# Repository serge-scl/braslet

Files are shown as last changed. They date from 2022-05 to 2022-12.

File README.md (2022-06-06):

Here I have collected calculations and drawings of a project for creating a device for removing disposable medical gloves with subsequent storage, accounting and disposal. This procedure is necessary to avoid a significant risk of infection during the work of medical staff. Various visual aids here offer a written and illustrated procedure on how to properly remove a disposable glove to avoid contact with a contaminated surface. However, the human factor suggests that sooner or later a mistake happens. This possibility is exacerbated by the factor of fatigue and stress.
The root directory contains files where I make various calculations. The earliest calculations related to the overall dimensions of the bracelet and its details relative to the size of the coverage of a man's or woman's wrist. These calculations cannot be called accurate. These are just some starting points.
Another group of calculations concerned the ability to determine the forces that a pneumatic mechanism must create for successful operation. This calculation showed that the range can vary quite widely. In the future, using differential equations will allow us to find more optimal values.
And the third type of calculation is the calculation of the solenoid valve that controls the operation of the suction cup. I tried to verify these calculations as far as possible.
The designCAD folder contains drawings in an open format. This work has not yet been completed in its entirety. So far, there are no drawings of the case, the upper and lower parts of the entire device, and it remains to be done. In the upper part there will be a working niche with a bracelet, and receivers and micropumps working with it. At the bottom there will be a negative pressure fan and storage for used gloves. So far, only part of the drawings of the bracelet have been made. This is a vacuum chamber with a solenoid valve and part of a pneumatic drive. All this is still in the form of separate parts without assembly. In the near future, we plan to complete the vacuum line and pneumatic drive.
Kicad pcb will contain two PCBs in two separate projects. This is a power control unit for the suction cup valve and a sensor unit that registers the correct touch of the hand with the glove. How the PCBs are attached can be seen in the sub_asstmbly/solenoid_in_chamb01 file. The inputs and outputs of these blocks are made in such a way that various types of microcontrollers can be connected. I did not finish the topology of the circuits, since the type of connectors may still be different.

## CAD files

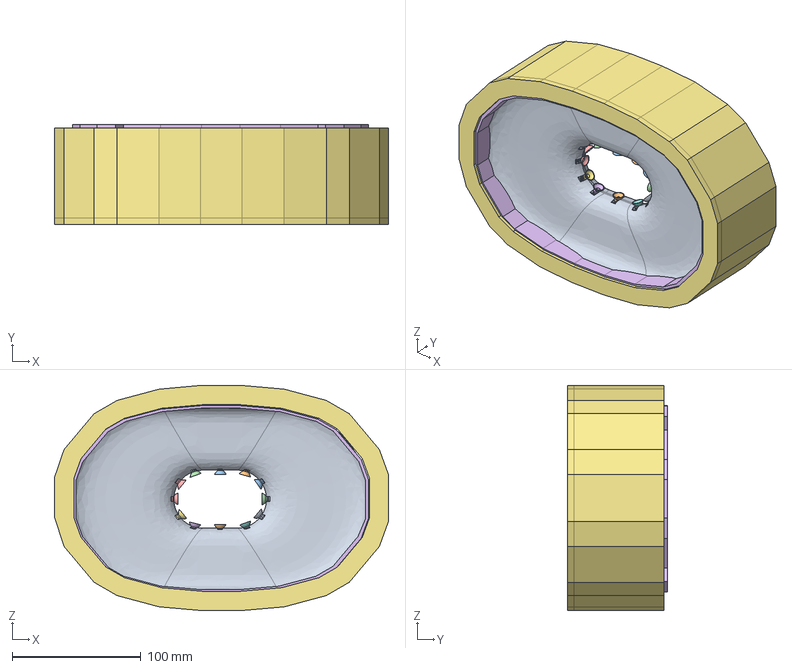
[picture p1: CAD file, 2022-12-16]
design CAD/sub_assembly/md_shell_asm01.FCStd
259.6 x 77.7 x 175.0 mm
lips02_001
cup04_001
cup04_002
cup04_003
cup04_004
cup04_005
cup04_006
cup04_007
cup04_008
cup04_009
cup04_010
cup04_011
cup04_012
btm_spr_modl_sh03_001
top_spr_modl_shell01_001

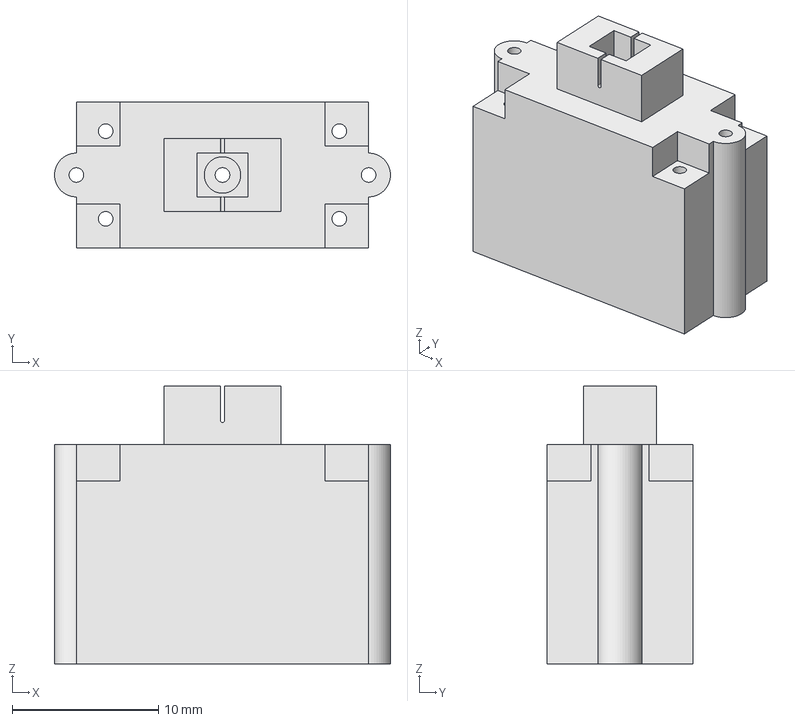
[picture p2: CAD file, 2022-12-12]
design CAD/shell_chamb12.FCStd
23.0 x 10.0 x 19.0 mm

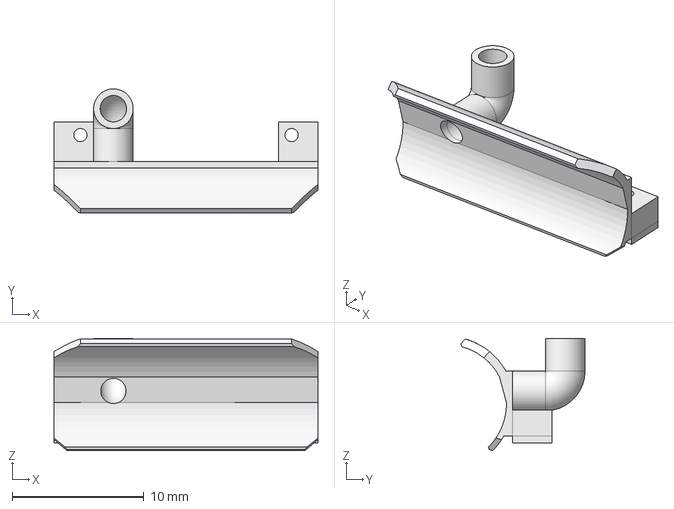
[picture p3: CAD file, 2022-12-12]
design CAD/actuator8_piston.FCStd
20.0 x 9.41 x 8.51 mm

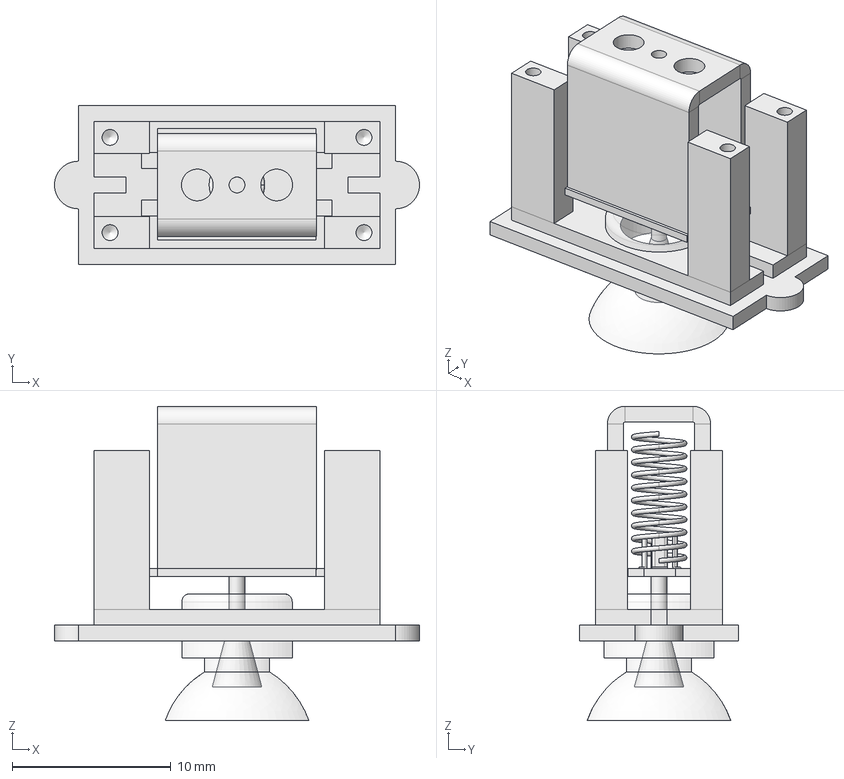
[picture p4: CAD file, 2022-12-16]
design CAD/sub_assembly/valve_floor_spr_scup01.FCStd
23.0 x 10.0 x 19.8 mm
suct_chamb_floor05_001
cup04_001
spring_valve01_001
tongue_sucker_001
el_magnetcore03_001
valve11_001

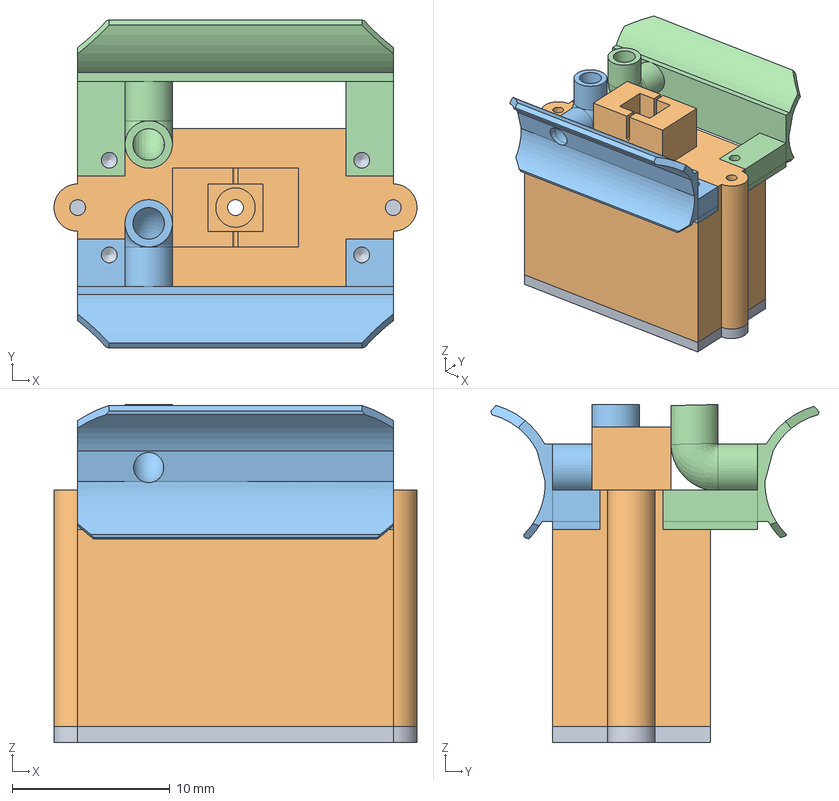
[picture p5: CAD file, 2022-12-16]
design CAD/sub_assembly/top_assmbl_vacuum_ch1.FCStd
23.0 x 20.8 x 21.4 mm
suct_chamb_floor05_001
shell_chamb12_001
actuator8_piston_001
actuator8_pistonPCBside_001

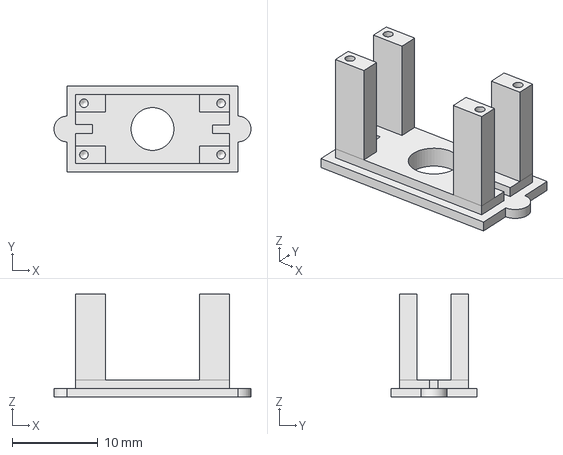
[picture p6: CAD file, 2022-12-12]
design CAD/suct_chamb_floor05.FCStd
23.0 x 10.0 x 12.0 mm

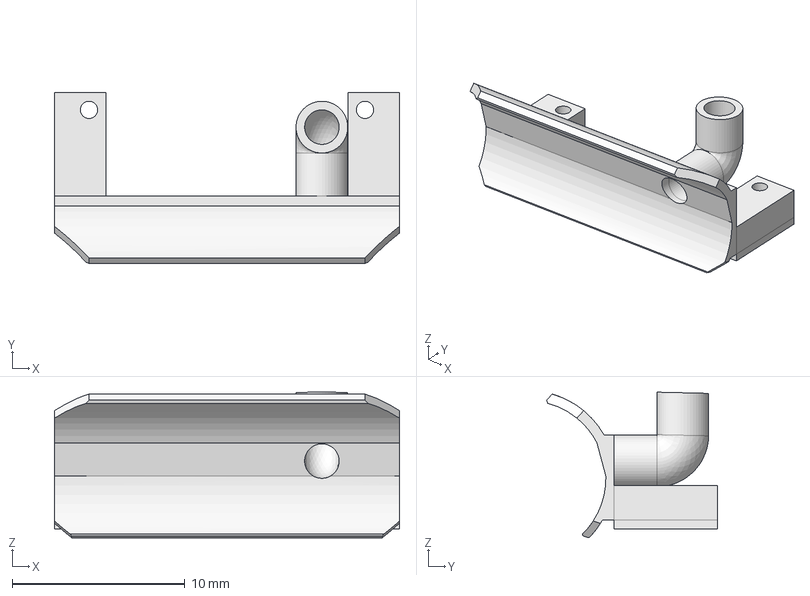
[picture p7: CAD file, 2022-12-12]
design CAD/actuator8_pistonPCBside.FCStd
20.0 x 9.90 x 8.45 mm

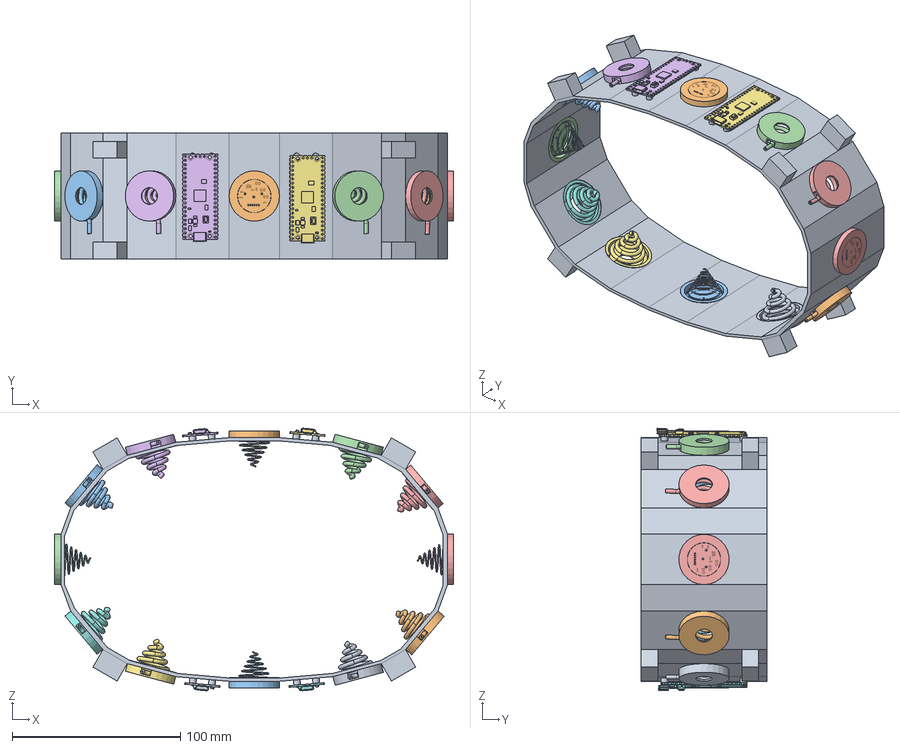
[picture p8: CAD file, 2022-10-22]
design CAD/sub_assembly/spr_mdl_bottm_cvr01.FCStd
237.4 x 75.0 x 156.3 mm
btm_spr_modl_sh03_001
con_spring_sens_sct01_001
con_spring_sens_sct01_002
con_spring_sens_sct01_003
con_spring_sens_sct01_004
con_spring_pip_sct01_001
con_spring_pip_sct01_002
con_spring_pip_sct01_003
con_spring_pip_sct01_004
con_spring_pip_sct01_005
con_spring_pip_sct01_006
con_spring_pip_sct01_007
con_spring_pip_sct01_008
Raspberry_Pi_Pico_001
Raspberry_Pi_Pico_002
Raspberry_Pi_Pico_003
Raspberry_Pi_Pico_004

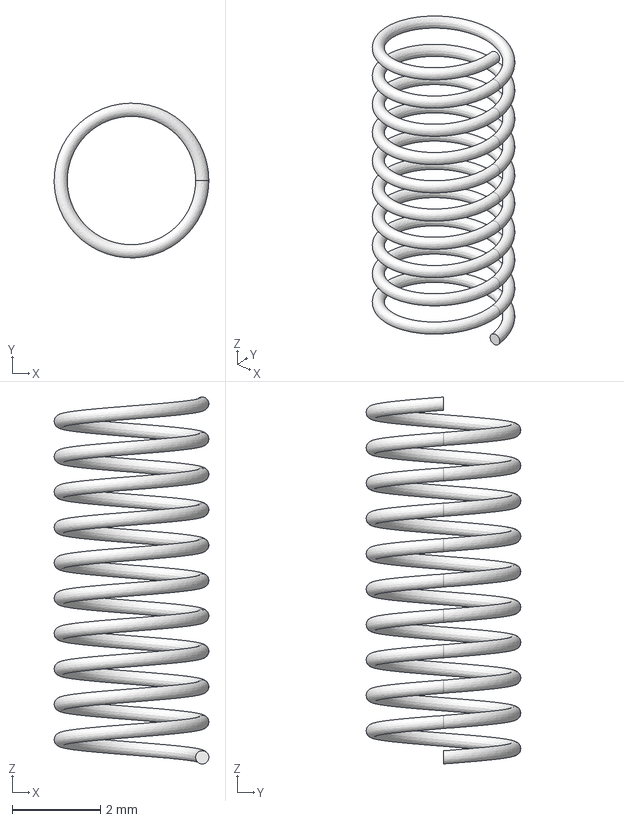
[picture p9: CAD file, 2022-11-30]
design CAD/spring_valve01.FCStd
3.50 x 3.50 x 8.30 mm

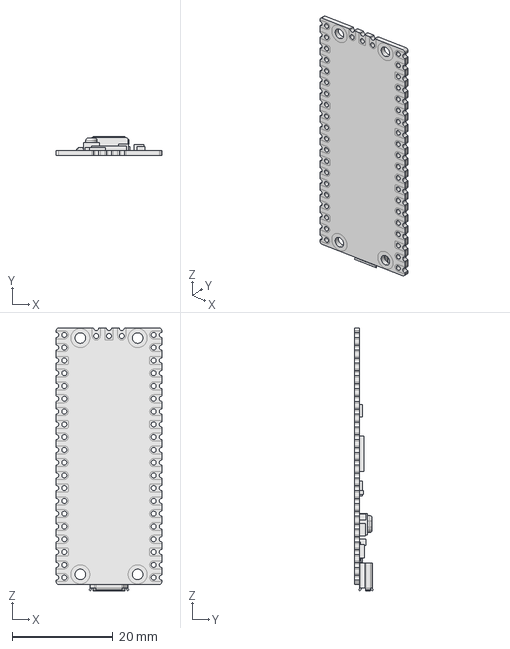
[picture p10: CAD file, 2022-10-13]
design CAD/sub_assembly/Raspberry_Pi_Pico.FCStd
21.0 x 3.73 x 52.3 mm

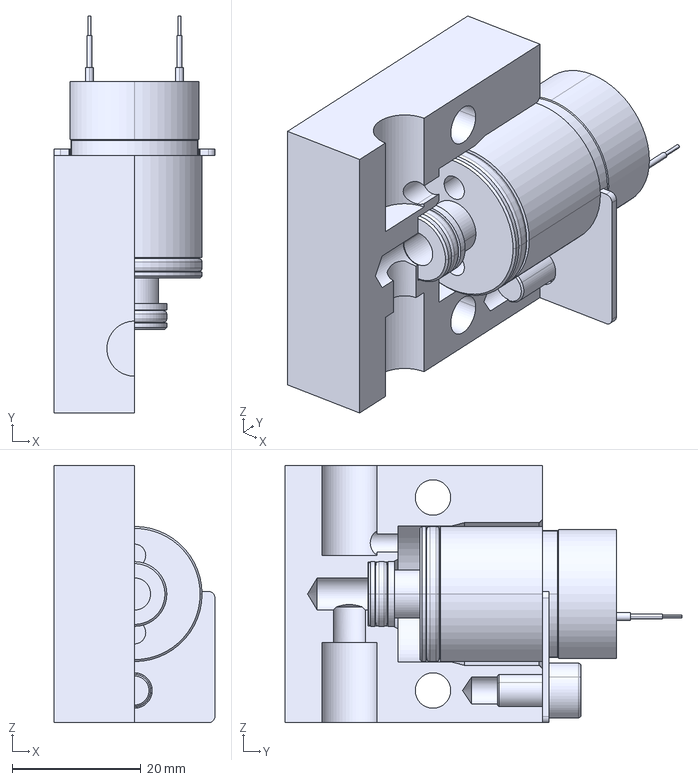
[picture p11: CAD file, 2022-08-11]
design CAD/sub_assembly/va_204_1_mont_plt.FCStd
25.0 x 61.7 x 40.0 mm

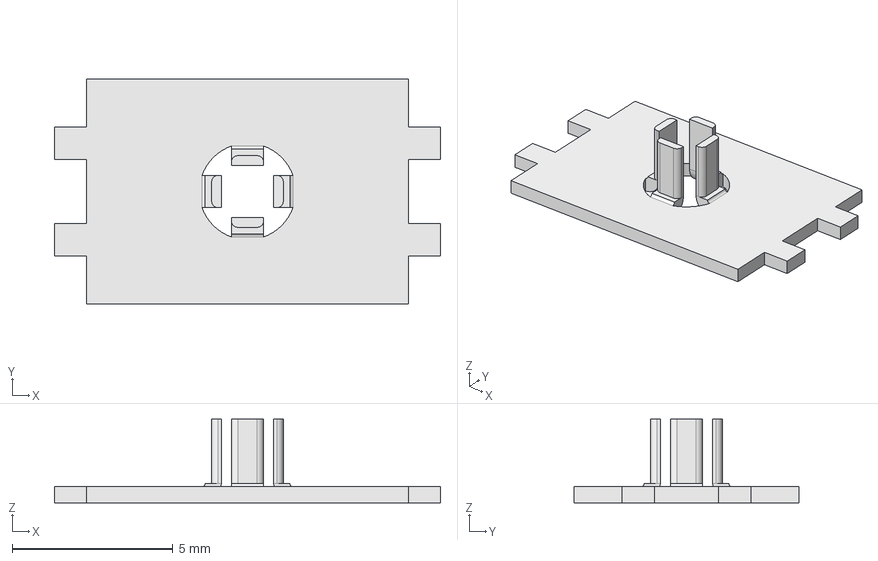
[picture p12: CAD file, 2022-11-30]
design CAD/valve11.FCStd
12.0 x 7.00 x 2.60 mm

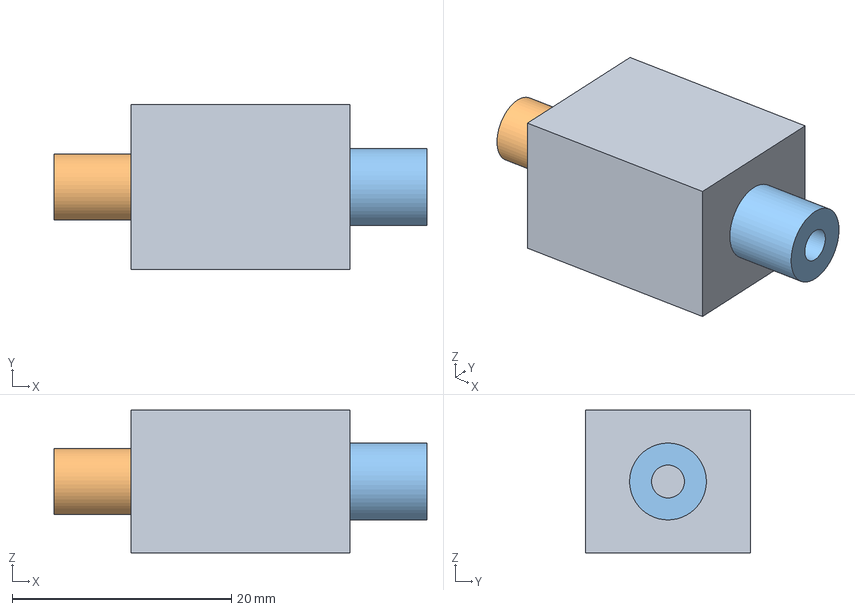
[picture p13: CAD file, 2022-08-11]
design CAD/sub_assembly/valve0520D.FCStd
34.0 x 15.0 x 13.0 mm
Tube
Tube001

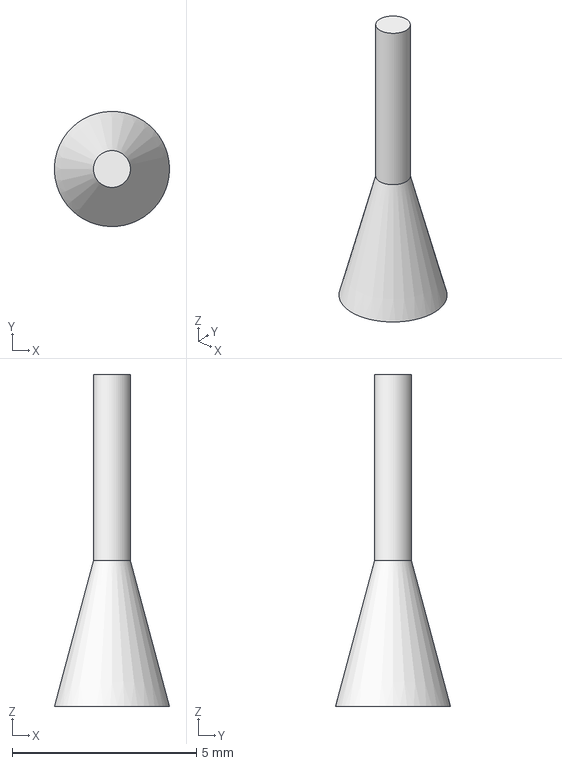
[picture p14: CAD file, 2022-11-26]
design CAD/tongue_sucker.FCStd
3.12 x 3.12 x 9.00 mm

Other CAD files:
design CAD/cup04.FCStd
design CAD/sub_assembly/claster_feed_ring03.FCStd
design CAD/btm_spr_modl_sh03.FCStd
design CAD/sub_assembly/con_spring_pip_sct01.FCStd
design CAD/actuator8.FCStd
design CAD/actuator8_side.FCStd
design CAD/branch_pipe_tee01.FCStd
design CAD/branch_pipe_tee0_feeder01.FCStd
design CAD/bush_feeder03.FCStd
design CAD/bush_simply02.FCStd
design CAD/coil_pins01.FCStd
design CAD/coil_pins02.FCStd
design CAD/con_pip_spring_sokt01.FCStd
design CAD/con_spring_plp01.FCStd
design CAD/con_spring_sockt01.FCStd
design CAD/con_spring_stl01.FCStd
design CAD/el_magnetcore03.FCStd
design CAD/frame_spring03.FCStd
design CAD/lips02.FCStd
design CAD/magn_coil03.FCStd
design CAD/pin_spring_fix01.FCStd
design CAD/pip_feed_ring05.FCStd
design CAD/pip_feed_ring06.FCStd
design CAD/screw01.FCStd
design CAD/spring_stop_01.FCStd
design CAD/sub_assembly/Ring_pneum_act01.FCStd
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

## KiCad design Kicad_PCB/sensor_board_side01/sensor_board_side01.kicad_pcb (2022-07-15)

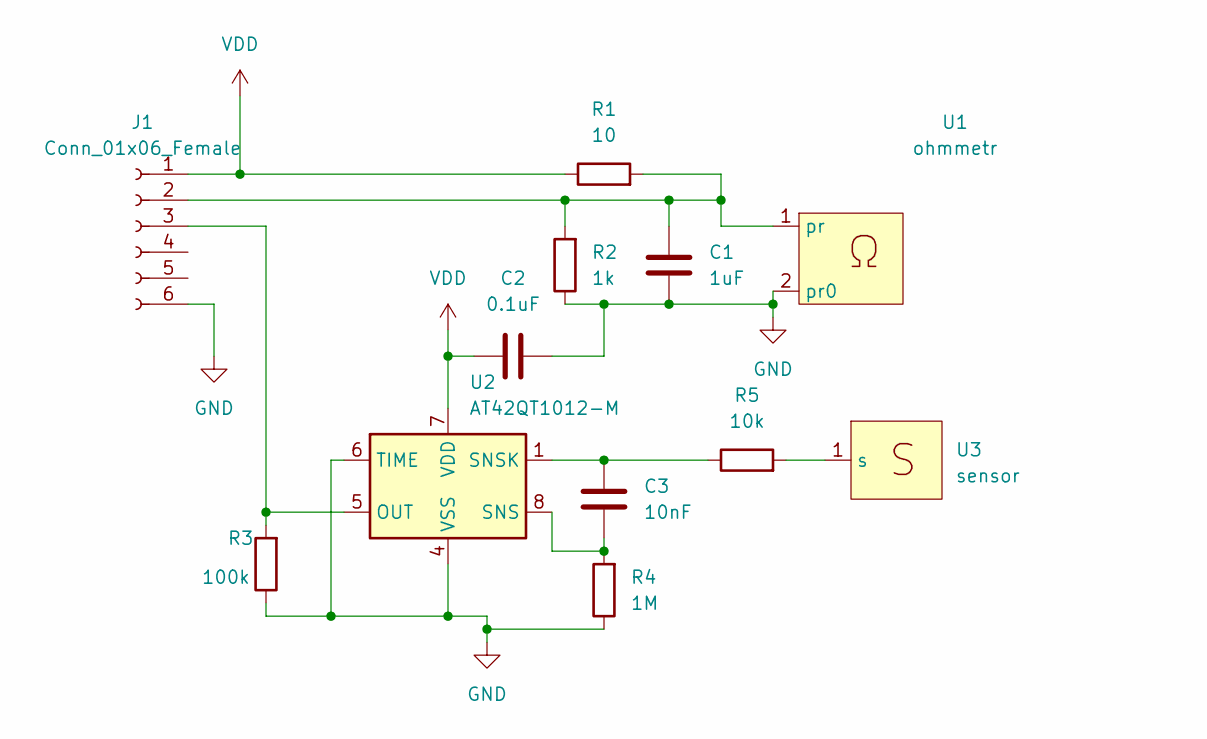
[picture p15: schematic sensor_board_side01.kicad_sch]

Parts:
C1: 1uF; C_0805_2012Metric
C2: 0.1uF; C_0805_2012Metric
C3: 10nF; C_0805_2012Metric
J1: Conn_01x06_Female; Hirose_DF13-06P-1.25DSA_1x06_P1.25mm_Vertical
R1: 10; R_0402_1005Metric
R2: 1k; R_0402_1005Metric
R3: 100k; R_0402_1005Metric
R4: 1M; R_0402_1005Metric
R5: 10k; R_0402_1005Metric
U1: ohmmetr; ohm_metr
U2: AT42QT1012-M; DFN-8-1EP_2x2mm_P0.5mm_EP0.9x1.5mm
U3: sensor; toch_sens

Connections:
GND: C1.2, C2.2, J1.6, R2.1, R3.1, R4.1, U1.2 (pr0), U2.4 (VSS), U2.6 (TIME), U2.9 (VSS)
unnamed: C1.1, J1.2, R1.2, R2.2, U1.1 (pr)
unnamed: C3.1, R4.2, U2.8 (SNS)
unnamed: C3.2, R5.1, U2.1 (SNSK)
unnamed: J1.3, R3.2, U2.5 (OUT)
unnamed: R5.2, U3.1 (s)
VDD: C2.1, J1.1, R1.1, U2.7 (VDD)

Board: 2 copper layers, 12 parts (1 on the bottom side), 7 nets, no tracks yet.

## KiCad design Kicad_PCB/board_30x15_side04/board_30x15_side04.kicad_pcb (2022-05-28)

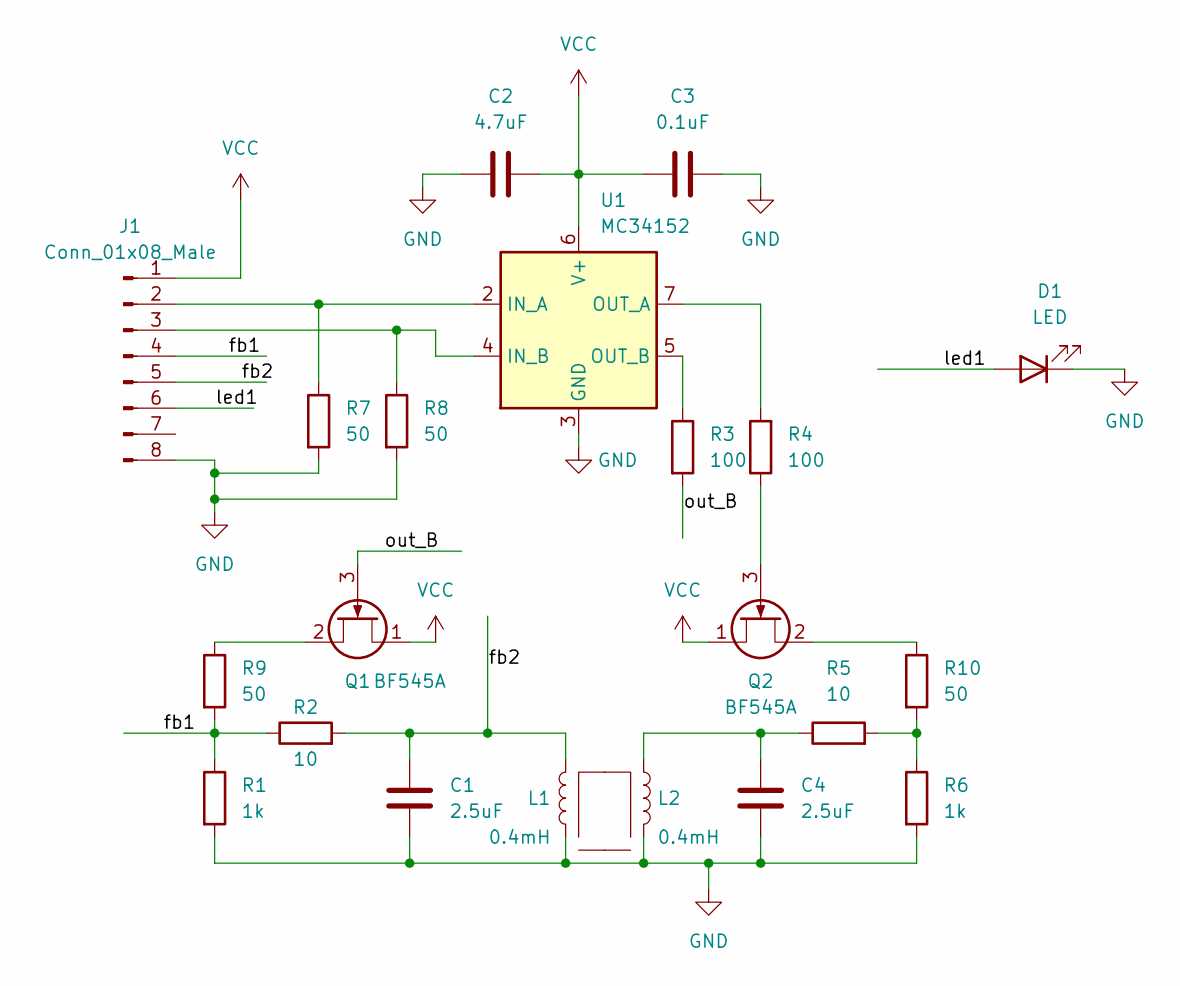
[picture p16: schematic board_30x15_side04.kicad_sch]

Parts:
C1, C4: 2.5uF; C_0805_2012Metric
C2: 4.7uF; C_0805_2012Metric
C3: 0.1uF; C_0805_2012Metric
D1: LED; LED_D1.8mm_W1.8mm_H2.4mm_Horizontal_O1.27mm_Z1.6mm
J1: Conn_01x08_Male; Hirose_DF13-08P-1.25DSA_1x08_P1.25mm_Vertical
L1, L2: 0.4mH; sole_coil
Q1, Q2: BF545A; SOT-23
R1, R6: 1k; R_0402_1005Metric
R2, R5: 10; R_0402_1005Metric
R3, R4: 100; R_0402_1005Metric
R7, R8, R9, R10: 50; R_0402_1005Metric
U1: MC34152; SOIC-8_3.9x4.9mm_P1.27mm

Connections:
/fb1: J1.4, R1.1, R2.1, R9.2
/fb2: C1.1, J1.5, L1.1, R2.2
/led1: D1.2 (A), J1.6
/out_B: Q1.3 (G), R3.2
GND: C1.2, C2.1, C3.2, C4.2, D1.1 (K), J1.8, L1.2, L2.2, R1.2, R6.2, R7.2, R8.2, U1.3 (GND)
unnamed: C4.1, L2.1, R5.1
unnamed: J1.2, R7.1, U1.2 (IN_A)
unnamed: J1.3, R8.1, U1.4 (IN_B)
unnamed: Q1.2 (D), R9.1
unnamed: Q2.2 (D), R10.1
unnamed: Q2.3 (G), R4.1
unnamed: R3.1, U1.5 (OUT_B)
unnamed: R4.2, U1.7 (OUT_A)
unnamed: R5.2, R6.1, R10.2
VCC: C2.2, C3.1, J1.1, Q1.1 (S), Q2.1 (S), U1.6 (V+)

Board: 2 copper layers, 21 parts (2 on the bottom side), 15 nets, no tracks yet.

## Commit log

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2021-07-13 back cover with feeder
    [side_tap08.FCStd]
2021-07-13 cover with plug
    [side_tap06.FCStd]
2021-07-13 vacuum transfer tube - spring
    [vacuum_pip04.FCStd]
2021-07-13 magnetic valve armature
    [valve11.FCStd]
2021-07-13 rubber valve nipple
    [ribbon02.FCStd]
2021-07-13 vacuum chamber floor
    [suct_chamb_floor05.FCStd]
2021-07-13 suction cup
    [cup04.FCStd]
2021-07-13 vacuum chamber shell
    assembly with coil contacts and pneumatic line
    [shell_chamb10.FCStd]
2021-07-13 magnetic coil
    [magn_coil03.FCStd]
2021-07-13 magnetic core
    [el_magnetcore03.FCStd]
2021-07-13 assembly floor and suction cup
    [cup_floor05.FCStd]
2021-07-13 magnetic coil contact
    [coil_pins01.FCStd]
2021-07-13 direct air line
    [bush_simply01.FCStd]
2021-07-13 assembly of pneumatic actuator
    [actuator8.FCStd]
2021-07-13 bottom of the pneumatic actuator
    [actuator7.FCStd]
2021-07-13 top of the pneumatic actuator
    [actuator6.FCStd]
2021-07-13 actuator part
    [actuator07.FCStd]
2021-07-13 actuator connection
    [actuator04.FCStd]
2021-07-17 feeder tap pressure air
    [press_feeder_tap01.FCStd]
2021-07-17 air line with feeder inlet
    [bush_feeder02.FCStd]
2021-07-17 assembly of the chamber 2
    assembly of the shell of the vacuum chamber with a feeder
    [shell_chamb11.FCStd]
2021-07-18 top fastener
    [fasteners01.FCStd]
2021-07-18 min dim feeder
    [press_feeder_tap01.FCStd]
2021-07-18 min dim fd chamb
    [shell_chamb11.FCStd]
2021-07-19 suspension assembly
    [shell_chamb12.FCStd]
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2021-07-30 pcb board open
    [board03.kicad_pcb, board03.sch]
2021-07-30 coil and all
    [board03.kicad_pcb, board03.sch]
2021-07-31 cap toch sensor
    [board03.kicad_pcb, board03.sch]
2021-07-31 sensor Vlt
    [board03.kicad_pcb, board03.sch]
2021-08-29 kicad correct in now git
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2022-02-10 valve spring CAD drawing
    [ribbon02.FCStd, spring_valve01.FCStd]
2022-02-14 solenoid calculation error fix
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2022-02-20 new magnet core
    [el_magnetcore03.FCStd]
2022-02-22 new magnet coil sizes
    [magn_coil03.FCStd]
2022-02-24 new dimensions vacuum chamber
    [shell_chamb12.FCStd]
2022-02-25 platform for magnet
    [shell_chamb12.FCStd]
2022-02-26 spring stop washer
    [el_magnetcore03.FCStd, spring_stop_01.FCStd]
2022-02-27 pin for spring
    [pin_spring_fix01.FCStd, shell_chamb12.FCStd]
2022-02-28 cross valve
    [valve11.FCStd]
2022-03-01 new vacuum chamber floor
    [suct_chamb_floor05.FCStd]
2022-03-03 new suction cup
    [cup04.FCStd]
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2022-03-08 three-section actuator 9 mm
    [actuator8.FCStd]
2022-03-10 side part of the actuator
    [actuator8_side.FCStd]
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2022-03-22 ellipse shape vacuum tube
    [vacuum_pip_ell04.FCStd]
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2022-04-06 branch pipe tee vacuum
    [branch_pipe_tee01.FCStd]
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2022-04-10 frame spring upgrade middle fix
    [frame_spring03.FCStd]
2022-04-13 shell chamb 12 add brackets
    [shell_chamb12.FCStd]
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2022-04-18 pip for air pressure 4x4
    [actuator8_piston.FCStd, actuator8_pistonPCBside.FCStd]
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2022-04-20 magnet coil 70 wire
    [magn_coil03.FCStd]
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2022-04-24 shell chamb 12 error
    [shell_chamb12.FCStd]
2022-04-25 assembly for drilling fasteners
    [top_assmbl_vacuum_ch1.FCStd]
2022-04-26 assemble: solenoid, coil and chamber
    [solenoid_in_chamb01.FCStd]
2022-04-27 valve, suction cup, floor and spring
    [valve_floor_spr_scup01.FCStd]
2022-04-28 valve 14 mm ln
    [valve11.FCStd, valve_floor_spr_scup01.FCStd]
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2022-05-09 PCB foot and connect
    [shell_chamb12.FCStd, solenoid_in_chamb01.FCStd, top_assmbl_vacuum_ch1.FCStd]
2022-05-10 3 coil pins and ground
    [coil_pins01.FCStd, coil_pins02.FCStd]
2022-05-10 pins and ground 2 correct
    [coil_pins01.FCStd, coil_pins02.FCStd, shell_chamb12.FCStd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]
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2022-05-29 sensors board 3 try
    [sensor_board_side01.kicad_pcb, sensor_board_side01.kicad_sch]
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2022-07-05 spring suspension pls cad
    [con_spring_plp01.FCStd, con_spring_stl01.FCStd]
2022-07-08 top loading module shell
    [top_spr_modl_shell01.FCStd]
2022-07-11 inner wrapper with holes
    [btm_spr_modl_sh03.FCStd]
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2022-07-15 conic spring in sockets with PCB
    [con_pip_spring_sokt01.FCStd, con_spring_pip_sct01.FCStd, con_spring_sens_sct01.FCStd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]
2022-07-16 spring module bottom cover
    [con_pip_spring_sokt01.FCStd, con_spring_pip_sct01.FCStd, spr_mdl_bottm_cvr01.FCStd]
2022-07-22 cover module shell ass
    [md_shell_asm01.FCStd]
2022-07-24 cover module shell assm 2 top
    [md_shell_asm01.FCStd]
2022-07-28 solenoid with coils and pin
    [top_assmbl_vacuum_ch1.FCStd]
2022-08-02 pip feeders ring cluster
    [claster_feed_ring03.FCStd, pip_feed_ring05.FCStd, pip_feed_ring06.FCStd]
2022-08-05 pip feeders cluster 3 mm
    [claster_feed_ring03.FCStd, pip_feed_ring05.FCStd, pip_feed_ring06.FCStd]
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2022-10-13 Raspberry Pi Pico cad
    [Raspberry_Pi_Pico.FCStd]
2022-10-20 Raspberry Pi Pico cad fix to asm
    [btm_spr_modl_sh03.FCStd, spr_mdl_bottm_cvr01.FCStd]
2022-10-22 Raspberry Pi Pico 3 pcb add
    [spr_mdl_bottm_cvr01.FCStd]
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2022-11-24 new idea of cup with tongue
    [cup04.FCStd]
2022-11-26 tongue in sub assembly
    [cup04.FCStd, tongue_sucker.FCStd, valve_floor_spr_scup01.FCStd]
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2022-12-12 new design of vacuum chamber
    [actuator8_piston.FCStd, actuator8_pistonPCBside.FCStd, shell_chamb12.FCStd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]
2022-12-16 updating the vacuum chamber in assemblies
    [md_shell_asm01.FCStd, top_assmbl_vacuum_ch1.FCStd, valve_floor_spr_scup01.FCStd]
